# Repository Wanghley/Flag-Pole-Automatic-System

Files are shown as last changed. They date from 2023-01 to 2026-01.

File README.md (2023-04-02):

<!-- Improved compatibility of back to top link: See: https://github.com/othneildrew/Best-README-Template/pull/73 -->

<!--
*** Thanks for checking out the Best-README-Template. If you have a suggestion
*** that would make this better, please fork the repo and create a pull request
*** or simply open an issue with the tag "enhancement".
*** Don't forget to give the project a star!
*** Thanks again! Now go create something AMAZING! :D
-->

<!-- PROJECT SHIELDS -->
<!--
*** I'm using markdown "reference style" links for readability.
*** Reference links are enclosed in brackets [ ] instead of parentheses ( ).
*** See the bottom of this document for the declaration of the reference variables
*** for contributors-url, forks-url, etc. This is an optional, concise syntax you may use.
*** https://www.markdownguide.org/basic-syntax/#reference-style-links
-->
[][contributors-url]
[][forks-url]
[][stars-url]
[][issues-url]
[][license-url]
[][linkedin-url]

<!-- PROJECT LOGO -->
<br />
<div align="center">
  <a href="https://github.com/Wanghley/Flag-Pole-Automatic-System">
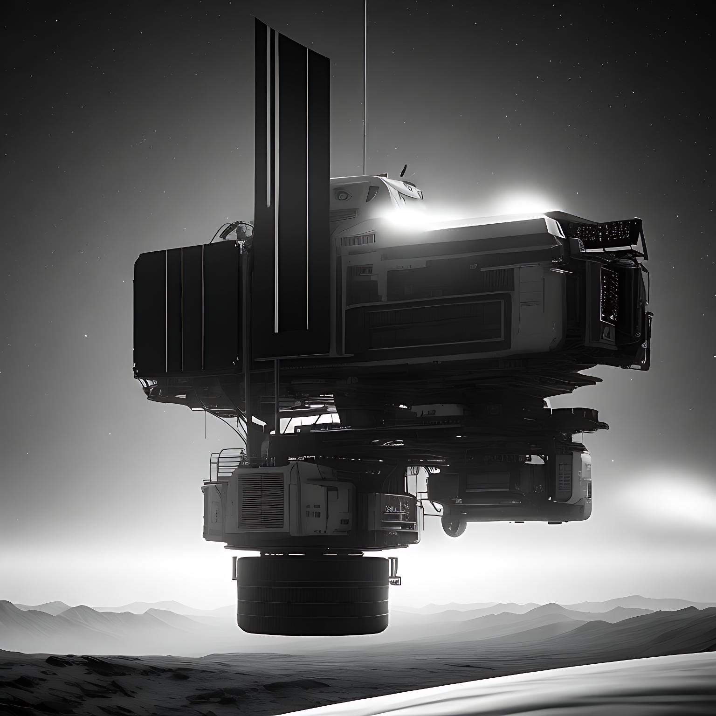
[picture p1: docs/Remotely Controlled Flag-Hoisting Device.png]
    
  </a>

  <h3 align="center">Remotely Controlled Flag-Hoisting Device</h3>

  <p align="center">
    Revolutionizing the way any institution hoists its flags! Our team of aspirant engineers at the Duke Pratt School of Engineering have designed a cutting-edge, remotely controlled flag-raising system that eliminates the need for manual labor and reduces costs for the university. With our innovative technology, flag heights can be adjusted safely and easily from any location with Wi-Fi access, making it a reliable and affordable solution. Say goodbye to labor costs and health risks associated with manual flag hoisting and hello to efficient and automated flag-raising with our state-of-the-art system!
    <br />
    <a href="https://github.com/Wanghley/Flag-Pole-Automatic-System"><strong>Explore the docs »</strong></a>
    <br />
    <br />
    <a href="https://github.com/Wanghley/Flag-Pole-Automatic-System">View Demo</a>
    ·
    <a href="https://github.com/Wanghley/Flag-Pole-Automatic-System/issues">Report Bug</a>
    ·
    <a href="https://github.com/Wanghley/Flag-Pole-Automatic-System/issues">Request Feature</a>
  </p>
</div>

<!-- TABLE OF CONTENTS -->
<details>
  <summary>Table of Contents</summary>
  <ol>
    <li>
      <a href="#about-the-project">About The Project</a>
      <ul>
        <li><a href="#built-with">Built With</a></li>
      </ul>
    </li>
    <li>
      <a href="#getting-started">Getting Started</a>
      <ul>
        <li><a href="#prerequisites">Prerequisites</a></li>
        <li><a href="#installation">Installation</a></li>
      </ul>
    </li>
    <li><a href="#usage">Usage</a></li>
    <li><a href="#roadmap">Roadmap</a></li>
    <li><a href="#contributing">Contributing</a></li>
    <li><a href="#license">License</a></li>
    <li><a href="#contact">Contact</a></li>
    <li><a href="#acknowledgments">Acknowledgments</a></li>
  </ol>
</details>

<!-- ABOUT THE PROJECT -->
## About The Project

[Product Name Screen Shot](https://example.com)

We built a remotely controlled, automatic, flag-hoisting device to service Duke University. Our client, Lee Clayton, a locksmithing specialist at Duke, has tasked us with creating an automatic, remotely-controlled system to more efficiently change flag heights for holidays and current events that require half-masting. When these special occasions arise, Duke currently relies on manual labor to lower or raise each flag one at a time.

This current system is suboptimal due to:

- Adverse weather conditions that prohibit access to flags
- Long walking time to all 16 flag poles around Duke’s campuses
- Each trip costs Duke $250 dollars, totaling to over $50,000 in the last decade.
- At the moment, the market only has automated machines that are attached to the flagpole with no remote control, an inadequate solution for the client as someone would still need to visit each pole. Our solution allows for remote control from any location with access to Duke Wi-Fi.

<p align="right">(<a href="#readme-top">back to top</a>)</p>

### Built With








<p align="right">(<a href="#readme-top">back to top</a>)</p>

<!-- GETTING STARTED -->
## Getting Started

This is an example of how you may give instructions on setting up your project locally.
To get a local copy up and running follow these simple example steps.

### Prerequisites

This is an example of how to list things you need to use the software and how to install them.
* npm
  ```sh
  npm install npm@latest -g
  ```

### Installation

_Below is an example of how you can instruct your audience on installing and setting up your app. This template doesn't rely on any external dependencies or services._

1. Get a free API Key at [https://example.com](https://example.com)
2. Clone the repo
   ```sh
   git clone https://github.com/your_username_/Project-Name.git
   ```
3. Install NPM packages
   ```sh
   npm install
   ```
4. Enter your API in `config.js`
   ```js
   const API_KEY = 'ENTER YOUR API';
   ```

<p align="right">(<a href="#readme-top">back to top</a>)</p>

<!-- USAGE EXAMPLES -->
## Usage

Use this space to show useful examples of how a project can be used. Additional screenshots, code examples and demos work well in this space. You may also link to more resources.

_For more examples, please refer to the [Documentation](https://example.com)_

<p align="right">(<a href="#readme-top">back to top</a>)</p>

<!-- ROADMAP -->
## Roadmap

- [x] Add Changelog
- [x] Add back to top links
- [ ] Add Additional Templates w/ Examples
- [ ] Add "components" document to easily copy & paste sections of the readme
- [ ] Multi-language Support
    - [ ] Chinese
    - [ ] Spanish

See the [open issues](https://github.com/othneildrew/Best-README-Template/issues) for a full list of proposed features (and known issues).

<p align="right">(<a href="#readme-top">back to top</a>)</p>

<!-- CONTRIBUTING -->
## Contributing

Contributions are what make the open source community such an amazing place to learn, inspire, and create. Any contributions you make are **greatly appreciated**.

If you have a suggestion that would make this better, please fork the repo and create a pull request. You can also simply open an issue with the tag "enhancement".
Don't forget to give the project a star! Thanks again!

1. Fork the Project
2. Create your Feature Branch (`git checkout -b feature/AmazingFeature`)
3. Commit your Changes (`git commit -m 'Add some AmazingFeature'`)
4. Push to the Branch (`git push origin feature/AmazingFeature`)
5. Open a Pull Request

<p align="right">(<a href="#readme-top">back to top</a>)</p>

<!-- LICENSE -->
## License

Distributed under the MIT License. See `LICENSE.txt` for more information.

<p align="right">(<a href="#readme-top">back to top</a>)</p>

<!-- CONTACT -->
## Contact

Your Name - [@your_twitter](https://twitter.com/your_username) - email@example.com

Project Link: [https://github.com/your_username/repo_name](https://github.com/your_username/repo_name)

<p align="right">(<a href="#readme-top">back to top</a>)</p>

<!-- ACKNOWLEDGMENTS -->
## Acknowledgments

Use this space to list resources you find helpful and would like to give credit to. I've included a few of my favorites to kick things off!

* [Choose an Open Source License](https://choosealicense.com)
* [GitHub Emoji Cheat Sheet](https://www.webpagefx.com/tools/emoji-cheat-sheet)
* [Malven's Flexbox Cheatsheet](https://flexbox.malven.co/)
* [Malven's Grid Cheatsheet](https://grid.malven.co/)
* [Img Shields](https://shields.io)
* [GitHub Pages](https://pages.github.com)
* [Font Awesome](https://fontawesome.com)
* [React Icons](https://react-icons.github.io/react-icons/search)

<p align="right">(<a href="#readme-top">back to top</a>)</p>

<!-- MARKDOWN LINKS & IMAGES -->
<!-- https://www.markdownguide.org/basic-syntax/#reference-style-links -->
[contributors-shield]: https://img.shields.io/github/contributors/Wanghley/Flag-Pole-Automatic-System.svg?style=for-the-badge
[contributors-url]: https://github.com/Wanghley/Flag-Pole-Automatic-System/graphs/contributors
[forks-shield]: https://img.shields.io/github/forks/Wanghley/Flag-Pole-Automatic-System.svg?style=for-the-badge
[forks-url]: https://github.com/Wanghley/Flag-Pole-Automatic-System/network/members
[stars-shield]: https://img.shields.io/github/stars/Wanghley/Flag-Pole-Automatic-System.svg?style=for-the-badge
[stars-url]: https://github.com/Wanghley/Flag-Pole-Automatic-System/stargazers
[issues-shield]: https://img.shields.io/github/issues/Wanghley/Flag-Pole-Automatic-System.svg?style=for-the-badge
[issues-url]: https://github.com/Wanghley/Flag-Pole-Automatic-System/issues
[license-shield]: https://img.shields.io/github/license/Wanghley/Flag-Pole-Automatic-System.svg?style=for-the-badge
[license-url]: https://github.com/Wanghley/Flag-Pole-Automatic-System/blob/master/LICENSE.md
[linkedin-shield]: https://img.shields.io/badge/-LinkedIn-black.svg?style=for-the-badge&logo=linkedin&colorB=555
[linkedin-url]: https://linkedin.com/in/wanghley
[product-screenshot]: images/screenshot.png
[Next.js]: https://img.shields.io/badge/next.js-000000?style=for-the-badge&logo=nextdotjs&logoColor=white
[Next-url]: https://nextjs.org/
[React.js]: https://img.shields.io/badge/React-20232A?style=for-the-badge&logo=react&logoColor=61DAFB
[React-url]: https://reactjs.org/
[Vue.js]: https://img.shields.io/badge/Vue.js-35495E?style=for-the-badge&logo=vuedotjs&logoColor=4FC08D
[Vue-url]: https://vuejs.org/
[Angular.io]: https://img.shields.io/badge/Angular-DD0031?style=for-the-badge&logo=angular&logoColor=white
[Angular-url]: https://angular.io/
[Svelte.dev]: https://img.shields.io/badge/Svelte-4A4A55?style=for-the-badge&logo=svelte&logoColor=FF3E00
[Svelte-url]: https://svelte.dev/
[Laravel.com]: https://img.shields.io/badge/Laravel-FF2D20?style=for-the-badge&logo=laravel&logoColor=white
[Laravel-url]: https://laravel.com
[Bootstrap.com]: https://img.shields.io/badge/Bootstrap-563D7C?style=for-the-badge&logo=bootstrap&logoColor=white
[Bootstrap-url]: https://getbootstrap.com
[JQuery.com]: https://img.shields.io/badge/jQuery-0769AD?style=for-the-badge&logo=jquery&logoColor=white
[JQuery-url]: https://jquery.com

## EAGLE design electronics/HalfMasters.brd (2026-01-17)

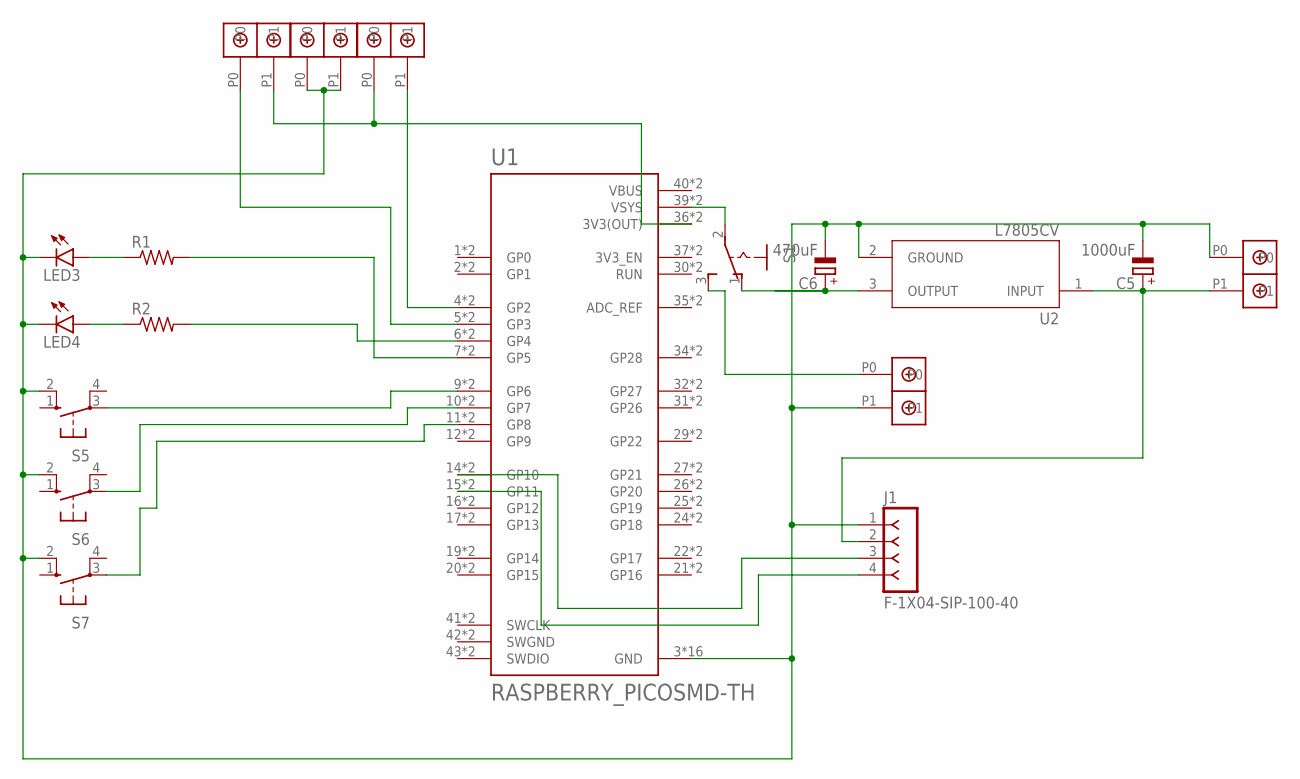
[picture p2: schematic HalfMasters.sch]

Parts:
C5: 1000uF; E2-5
C6: 470uF; E2-5
J1: F-1X04-SIP-100-40; SIP-100-04-40
LED3, LED4: LED5MM
R1, R2: R-US_0207/10; 0207/10
S1: 255SB
S5, S6, S7: 10-XX; B3F-10XX
U1: RASPBERRY_PICOSMD-TH; PICO-PKG
U2: L7805CV; TO255P1040X460X1968-3
U$1, U$2, U$3, U$4, U$5: DBCONN-1X2

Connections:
unnamed: R2.2, U1.6 (GP4), U1.P$6 (GP4)
unnamed: R1.2, U1.7 (GP5), U1.P$7 (GP5)
unnamed: S1.3 (S), U$5.P0
unnamed: J1.3, U1.14 (GP10), U1.P$14 (GP10)
unnamed: J1.4, U1.15 (GP11), U1.P$15 (GP11)
unnamed: S1.2, U1.39 (VSYS), U1.P$39 (VSYS)
unnamed: C6.+, S1.1 (O), U2.3 (OUTPUT)
unnamed: U1.36 (3V3(OUT)), U1.P$36 (3V3(OUT)), U$1.P1, U$3.P0
unnamed: U1.4 (GP2), U1.P$4 (GP2), U$3.P1
unnamed: U1.5 (GP3), U1.P$5 (GP3), U$1.P0
unnamed: LED3.A, R1.1
unnamed: LED4.A, R2.1
unnamed: C5.+, J1.2, U2.1 (INPUT), U$4.P1
unnamed: C5.-, C6.-, J1.1, LED3.K (C), LED4.K (C), S5.2 (S1), S6.2 (S1), S7.2 (S1), U1.3 (GND), U1.8 (GND), U1.13 (GND), U1.18 (GND), U1.23 (GND), U1.28 (GND), U1.33 (GND), U1.38 (GND), U1.P$3 (GND), U1.P$8 (GND), U1.P$13 (GND), U1.P$18 (GND), U1.P$23 (GND), U1.P$28 (GND), U1.P$33 (GND), U1.P$38 (GND), U2.2 (GROUND), U$2.P0, U$2.P1, U$4.P0, U$5.P1
unnamed: S5.3, U1.9 (GP6), U1.P$9 (GP6)
unnamed: S6.3, U1.10 (GP7), U1.P$10 (GP7)
unnamed: S7.3, U1.11 (GP8), U1.P$11 (GP8)
SWGND: U1.42 (SWGND), U1.P$42 (SWGND)
VBUS: U1.40 (VBUS), U1.P$40 (VBUS)

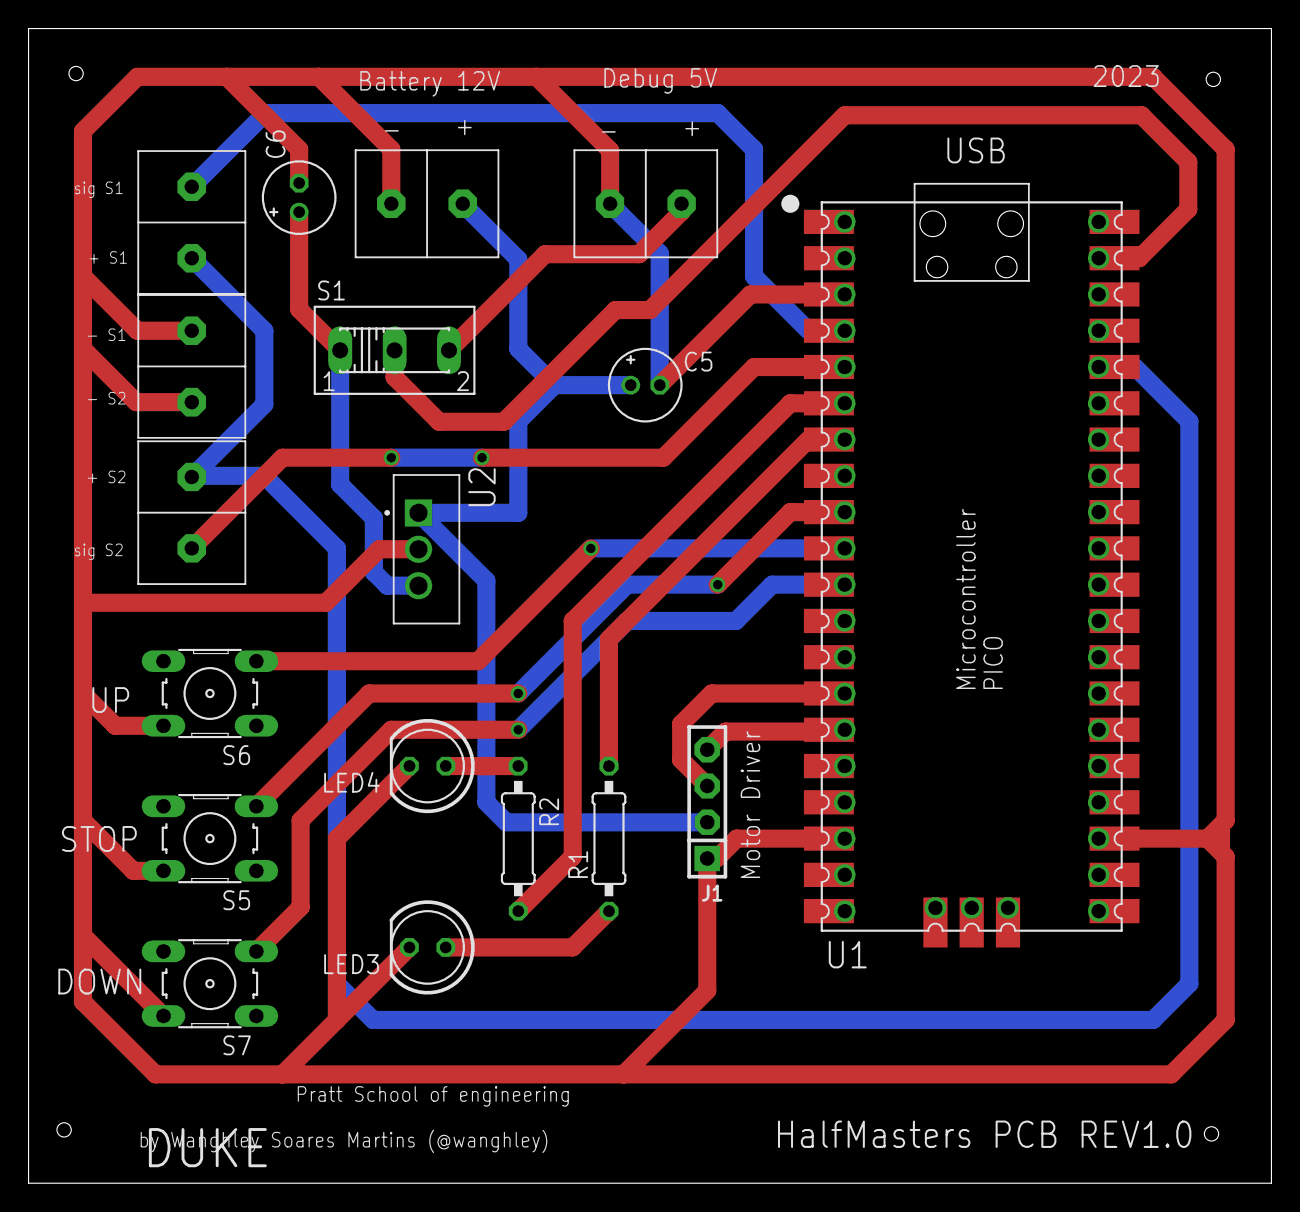
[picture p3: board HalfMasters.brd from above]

Board: 2 copper layers, 87.0 x 80.8 mm, 18 parts (0 on the bottom side), 19 nets.

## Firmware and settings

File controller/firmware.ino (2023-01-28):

#include <AccelStepper.h>
#include <EEPROM.h>

// Define stepper motor connections and motor interface type. Motor interface type must be set to 1 when using a driver:
#define dirPin 2
#define stepPin 3
#define motorInterfaceType 1
#define STEPS_PER_REV 1600 // steps needed for Nema 23
#define btnUP 6
#define btnDOWN 5
#define btnMIDDLE 7
#define btnMaintanance A3
#define ledON A4
#define ledMaintance A5
#define speed 3000

// Create a new instance of the AccelStepper class:
AccelStepper stepper = AccelStepper(motorInterfaceType, stepPin, dirPin);

double bottonStep = 0;
double upStep,downStep, current=0;
double up,down,middle;

void setup() {
  // Set the maximum speed and acceleration:
  stepper.setMaxSpeed(3000);
  stepper.setAcceleration(100000);

  Serial.begin(115200);

  pinMode(ledMaintance, OUTPUT);
  digitalWrite(ledMaintance, LOW);
  pinMode(ledON, OUTPUT);
  digitalWrite(ledON, LOW);

  pinMode(btnMaintanance, INPUT_PULLUP);
  pinMode(btnUP, INPUT_PULLUP);
  pinMode(btnDOWN, INPUT_PULLUP);

  pinMode(btnMIDDLE, INPUT_PULLUP);
  
  // Get storaged data from EEPROM
  up = readIntFromEEPROM(0);
  middle = readIntFromEEPROM(2);
  down = readIntFromEEPROM(4);

  // FOR DEBUG ONLY
  // Serial.println(up);
  // Serial.println(middle);
  // Serial.println(down);
}

void writeIntIntoEEPROM(int address, int number){ 
  byte byte1 = number >> 8;
  byte byte2 = number & 0xFF;
  EEPROM.write(address, byte1);
  EEPROM.write(address + 1, byte2);
}

// Read data from Arduino EEPROM
int readIntFromEEPROM(int address){
  byte byte1 = EEPROM.read(address);
  byte byte2 = EEPROM.read(address + 1);
  return (byte1 << 8) + byte2;
}

void setPos(int pos){ // 1 up, 0 middle, -1 down
  if(pos==1){
    if(current<up){
      while(stepper.isRunning()){}
      stepper.move((up-current));
      stepper.runToPosition();
      current = up;
    }
  }else if(pos==-1){ // TODO: Problem on lowering from up when passes by middle
    if(current>down){
      while(stepper.isRunning()){}
      stepper.move((down-current));
      stepper.runToPosition();
      current = down;
    }
  }else if(pos==0){
    if(current<middle){
      while(stepper.isRunning()){}
      stepper.move((middle-current));
      stepper.runToPosition();
      current = middle;
    }
    else{
      while(stepper.isRunning()){}
      stepper.move(-(current-middle));
      stepper.runToPosition();
      current = middle;
    }
  }

  // FOR DEBUG ONLY
  // Serial.println(current);
}

void blink(int port, int repetitions, int duration){
  for(int i=0;i<repetitions;i++){
    digitalWrite(port, HIGH);
    delay(200);
    digitalWrite(port, LOW);
    delay(200);
  } 
}

void loop() {
  // Set the target position:
  // stepper.moveTo(8000);
  // // Run to target position with set speed and acceleration/deceleration:
  // stepper.runToPosition();

  // delay(1000);

  // // Move back to zero:
  // stepper.moveTo(0);
  // stepper.runToPosition();

  // delay(1000);

  if(digitalRead(btnMaintanance)==0){
    digitalWrite(ledMaintance, HIGH);
    if(digitalRead(btnUP)==0 && !stepper.isRunning()){
      stepper.setSpeed(speed);
      stepper.move(STEPS_PER_REV);
      upStep += STEPS_PER_REV;
      current+=upStep;
      // FOR DEBUG ONLY
      // Serial.println(current);
      stepper.runToPosition();
      delay(40);
    }
    if(digitalRead(btnDOWN)==0  && !stepper.isRunning()){
      stepper.setSpeed(-speed);
      stepper.move(-STEPS_PER_REV);
      downStep += -STEPS_PER_REV;
      current+=downStep;
      // FOR DEBUG ONLY
      // Serial.println(current);
      stepper.runToPosition();
      delay(40);
    }
    if(digitalRead(btnMIDDLE)==0){
      up = upStep;
      down = abs(upStep+downStep);
      middle = (up-down)/2;

      // FOR DEBUG ONLY
      // Serial.println(up);
      // Serial.println(middle);
      // Serial.println(down);

      writeIntIntoEEPROM(0,up);
      writeIntIntoEEPROM(2,middle);
      writeIntIntoEEPROM(4,down);

      blink(ledMaintance,3,300);
    }
  }else{
    digitalWrite(ledMaintance, LOW);
    if(Serial.available() && up!=-1 && middle!=-1 && down!=-1){
      char c = Serial.read();
      if(c=='u'){
        setPos(1);
        Serial.println(1);    
      }else if(c=='d'){
        setPos(-1);
        Serial.println(-1);
      }else if(c=='m'){
        setPos(0);
        Serial.println(0);
      }
    }
  }
}

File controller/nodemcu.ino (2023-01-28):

/*
 *  Author: Wanghley Soares Martins (@wanghley)
 *
 */
 
#include "Arduino.h"
#include <ESP8266WiFi.h>
#include <WiFiClient.h>
#include <ESP8266WebServer.h>
#include <ESP8266mDNS.h>
#include <WiFiManager.h>         //https://github.com/tzapu/WiFiManager
#include <ArduinoJson.h>
#include <Stepper.h>
#include <EEPROM.h>
#include <SoftwareSerial.h>

// Define variables to be used 

 
ESP8266WebServer server(80);
SoftwareSerial s(3,1);
 
// Serving Hello world
void getHelloWord() {
    DynamicJsonDocument doc(512);
    doc["name"] = "Hello world";
    String buf;
    serializeJson(doc, buf);
    server.send(200, "application/json", buf);
}
// Serving Hello world
void getSettings() {
  // Allocate a temporary JsonDocument
  // Don't forget to change the capacity to match your requirements.
  // Use arduinojson.org/v6/assistant to compute the capacity.
  //  StaticJsonDocument<512> doc;
  // You can use DynamicJsonDocument as well
  DynamicJsonDocument doc(512);

  doc["ip"] = WiFi.localIP().toString();
  doc["gw"] = WiFi.gatewayIP().toString();
  doc["nm"] = WiFi.subnetMask().toString();

  if (server.arg("signalStrength")== "true"){
      doc["signalStrengh"] = WiFi.RSSI();
  }

  if (server.arg("chipInfo")== "true"){
      doc["chipId"] = ESP.getChipId();
      doc["flashChipId"] = ESP.getFlashChipId();
      doc["flashChipSize"] = ESP.getFlashChipSize();
      doc["flashChipRealSize"] = ESP.getFlashChipRealSize();
  }
  if (server.arg("freeHeap")== "true"){
      doc["freeHeap"] = ESP.getFreeHeap();
  }

  String buf;
  serializeJson(doc, buf);
  server.send(200, F("application/json"), buf);
}

void setPosition() {
  Serial.println();
  if (server.hasArg("plain")== false){ //Check if body received
    server.send(200, "text/plain", "Body not received");
    return;
  }

  // StaticJsonBuffer<200> jsonBuffer;
  // JsonObject& root = jsonBuffer.parseObject(server.arg("plain"));
  
  // String message = "Body received:\n";
  //         message += server.arg("plain");
  //         message += "\n";

  const char* json = server.arg("plain").c_str();
  DynamicJsonDocument doc(1024);
  deserializeJson(doc, json);

  String id = doc["id"];
  int pos = doc["pos"];

  if(id=="usa"){
    if(pos==1){
      s.println('u');
      String resp = "{id:"+id+",pos:"+pos+"}";
      server.send(201, "text/json", resp);
    }
    else if(pos==-1){
      s.println('d');
      String resp = "{id:"+id+",pos:"+pos+"}";
      server.send(201, "text/json", resp);
    }
    else if(pos==0){
      s.println('m');
      String resp = "{id:"+id+",pos:"+pos+"}";
      server.send(201, "text/json", resp);
    }else{
      String resp = "{\"error\": \"invalid option\"}";
      server.send(500, "text/json", resp);
    }
  }
  //Serial.println(message);
}
 
// Define routing
// Implement data json filtering
// https://github.com/esp8266/Arduino/issues/1670
void restServerRouting() {
    server.on("/", HTTP_GET, []() {
        server.send(200, F("text/html"),
            F("Welcome to the REST Web Server"));
    });
    server.on(F("/helloWorld"), HTTP_GET, getHelloWord);
    server.on(F("/settings"), HTTP_GET, getSettings);
    server.on(F("/set-position"), HTTP_POST, setPosition);
}
 
// Manage not found URL
void handleNotFound() {
  String message = "File Not Found\n\n";
  message += "URI: ";
  message += server.uri();
  message += "\nMethod: ";
  message += (server.method() == HTTP_GET) ? "GET" : "POST";
  message += "\nArguments: ";
  message += server.args();
  message += "\n";
  for (uint8_t i = 0; i < server.args(); i++) {
    message += " " + server.argName(i) + ": " + server.arg(i) + "\n";
  }
  server.send(404, "text/plain", message);
}
 
void setup(void) {
  Serial.begin(115200);
  s.begin(115200);
  WiFi.mode(WIFI_STA);
  WiFiManager wifiManager;
  wifiManager.setDebugOutput(false);
  //wifiManager.resetSettings();
  wifiManager.autoConnect("HalfMaster USA","1234567890");
  // Serial.println("connected :)");
 
  // Serial.print("IP address: ");
  // Serial.println(WiFi.localIP());
 
  // Activate mDNS this is used to be able to connect to the server
  // with local DNS hostmane esp8266.local
  // if (MDNS.begin("esp8266")) {
  //   Serial.println("MDNS responder started");
  // }
 
  // Set server routing
  restServerRouting();
  // Set not found response
  server.onNotFound(handleNotFound);
  // Start server
  server.begin();
  // Serial.println("HTTP server started");
}
 
void loop(void) {
  server.handleClient();
}

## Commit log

2022-10-19 feat: functional firmware for prototype using angular movement
2022-10-24 feat: insert automatic command to set up and down
2022-10-24 feat: full control of motion of the device
    TODO: needs to implement saving on EEPROM and set up remote control by IP address
2022-10-26 fix!: correct movement from top position to middle position
    Wrong movement command on moving from up to middle corrected
    [firmware.ino]
2022-10-26 fix: remove non-used variables
    remove variables not used in the context what of problem
    [firmware.ino]
2022-11-16 fix!: operational microcontroller kit functional w serial communication
    implemented communication to be received from nodemcu through wireless
    [firmware.ino]
2022-11-21 feat: implementation NEMA 23 + AccelStepper
    Implement AccelStepper library v1.61.0
    Default setings for NEMA 23 motor driver
    TB6600
2023-02-12 feat: initial code developed for pico W implementation
2023-03-20 feat: libraries for new components of motor drive added
2023-03-20 feat: initial functional code with pico platform
    functional code with basic implementation on the raspberry pi
    Only one hall effect sensor added
2023-03-23 feat: final rev 1 schematic of controller circuit
    [HalfMasters.sch]
2023-03-23 feat: rev 1 of the PCB designed ready
    [HalfMasters.brd]
2023-03-23 refactor: logo for PCB
2023-03-23 refactor: schematic needed libraries
2023-03-24 fix: change vias width to match Duke requirements
    [HalfMasters.brd]
2023-03-31 fix: 7805 position inverted vertically
    No problem on the design, but this change will allow the voltage regulator to be placed bend in the PCB
    [HalfMasters.brd]
2023-04-02 feat: insert docs to repository
2026-01-17 refacotr: code upload to github
    [HalfMasters.brd, HalfMasters.sch]

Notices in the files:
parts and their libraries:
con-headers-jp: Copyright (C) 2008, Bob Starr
